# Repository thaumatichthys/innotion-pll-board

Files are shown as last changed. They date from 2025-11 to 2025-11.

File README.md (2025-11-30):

# ADF4158 + YSGM556006 Test Board  

**Thanks Mr GPT for (some parts of) the readme**

**5.5–6.0 GHz PLL/VCO Synthesizer w/ RP2040 Control**

This project is a small test board built around the **Analog Devices ADF4158** fractional-N PLL and the **Innotion YSGM556006** VCO module to generate RF signals in the **5.5–6.0 GHz** range.  
An **RP2040 microcontroller** drives the PLL over SPI, making it easy to test frequency sweeps, chirps, or single-tone synthesis.

## ✨ Features
- **ADF4158 PLL**
  - Fractional-N synthesizer  
  - Supports various shapes of ramps / chirps  

- **Innotion YSGM556006 VCO**
  - Very low cost VCO ($1.5/ea)
  - 5.5–6.0 GHz tuning range  
 
- **External (off-board) VCO Option**
  - SMA connectors expose VTUNE and VCO IN

- **RP2040 Controller**
  - Sends SPI commands for programming the PLL  
  - USB serial for sending commands / updating configs  

- **Other Board Components**
  - Loop filter for PLL stabilization  
  - Clean reference input stage (TCXO) 

## 📐 Purpose
This test board is designed for experimenting with PLL/VCO behavior at ~6 GHz.  
Typical use cases:

- Testing ADF4158 chirp/ramp features  
- Characterizing VCO tuning curve  
- LO generation for mixers or radar experiments  
- Measuring lock time, phase noise, loop stability  
- Learning / verifying SPI programming sequences for the ADF4158

## 🧠 How It Works
1. The **RP2040** boots and configures the ADF4158 via SPI.  
2. The ADF4158 sets the **divider ratio + ramp settings**.  
3. The loop filter drives the VCO’s **tuning voltage**, closing the PLL.  
4. The YSGM556006 outputs ~5.5–6 GHz RF.  
5. Lock status is monitored via **MUXOUT** exposed on the board.

## 🔌 SPI Interface (RP2040 → ADF4158)
- **MOSI** – PLL data input  
- **SCLK** – SPI clock  
- **LE** – Latch enable for register load  
- **MUXOUT** – Readable lock detect for debugging  

## ⚠️ Notes / Limitations
- The Innotion YSGM556006 is a very low cost ($1.5/ea) VCO, and has poor performance. This board was an attempt to test the feasibility of its use in a PLL.
- This test board is **not** a finalized RF product — it’s meant for bench characterization.  
- Ensure your RF chain and measurement equipment can safely handle 5–6 GHz at around 0 dBm.

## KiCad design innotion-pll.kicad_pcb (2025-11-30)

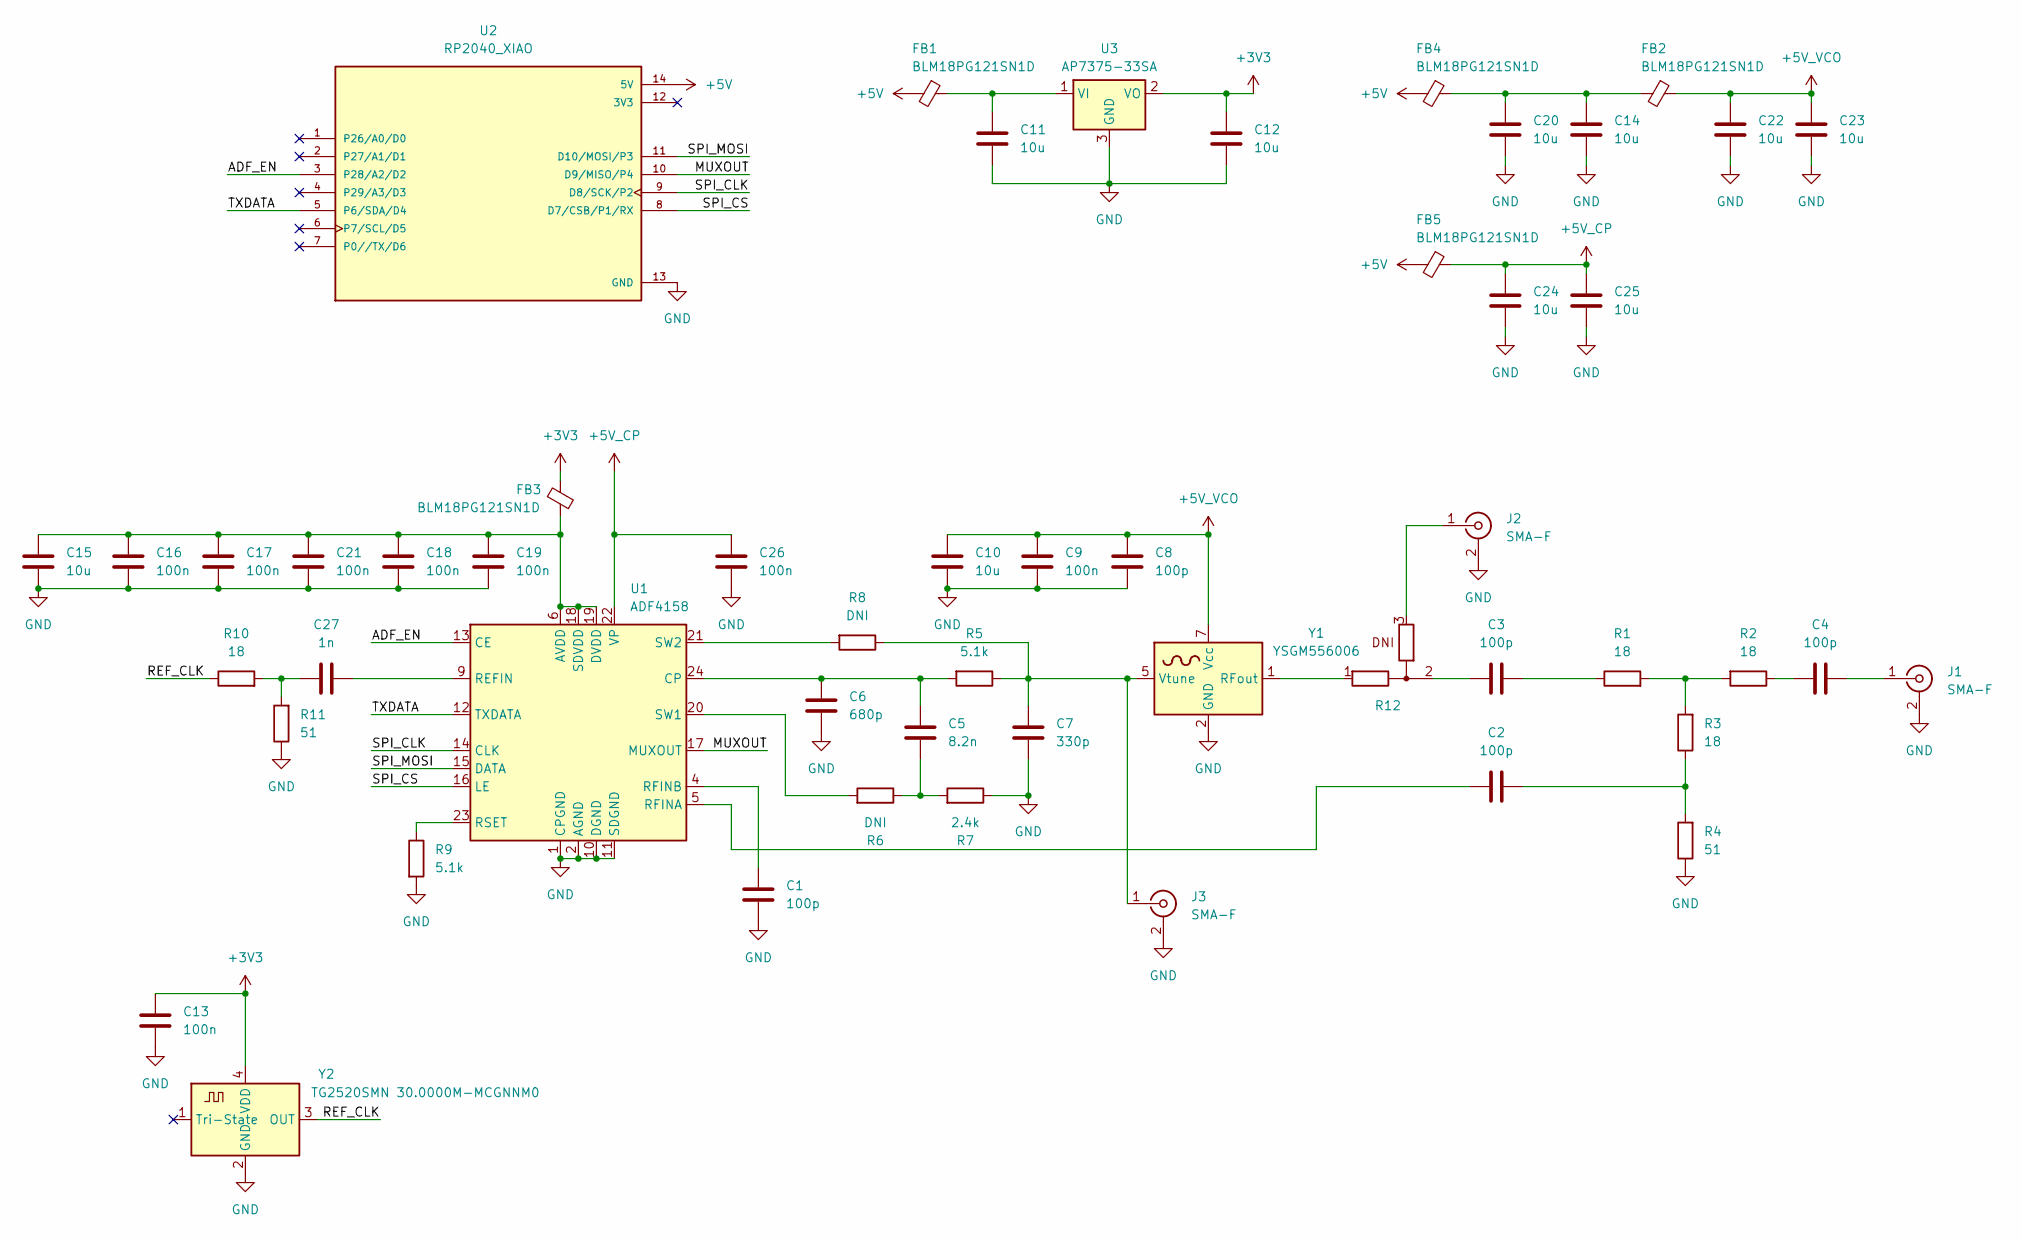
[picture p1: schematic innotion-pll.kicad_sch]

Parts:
C1, C2, C3, C4, C8: 100p; C_0402_1005Metric
C5: 8.2n; C_0402_1005Metric
C6: 680p; C_0402_1005Metric
C7: 330p; C_0402_1005Metric
C9, C13, C16, C17, C18, C19, C21, C26: 100n; C_0402_1005Metric
C10, C11, C12, C14, C15, C20, C22, C23, C24, C25: 10u; C_0805_2012Metric
C27: 1n; C_0402_1005Metric
FB1, FB2, FB3, FB4, FB5: BLM18PG121SN1D; L_0603_1608Metric_Pad1.05x0.95mm_HandSolder
J1, J2, J3: SMA-F; ADAMTECH_RF2-143-T-17-50-G
R1, R2, R3, R10: 18; R_0402_1005Metric
R4, R11: 51; R_0402_1005Metric
R5, R9: 5.1k; R_0402_1005Metric
R6, R8: DNI; R_0402_1005Metric
R7: 2.4k; R_0402_1005Metric
R12: R_0402_SELECT_MIRRORED
U1: ADF4158; LFCSP-24-1EP_4x4mm_P0.5mm_EP2.5x2.5mm
U2: RP2040_XIAO; MODULE_102010428; PARTREV 1.3
U3: AP7375-33SA; SOT-23
Y1: YSGM556006; INNOTION_VCO_MODULE_7x9mm
Y2: TG2520SMN 30.0000M-MCGNNM0; Oscillator_SMD_SeikoEpson_TG2520SMN-xxx-xxxxxx-4Pin_2.5x2.0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

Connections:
+3V3: C12.2, C13.2, FB3.1, U3.2 (VO), Y2.4 (VDD)
+5V: FB1.2, FB4.2, FB5.2, U2.14 (5V)
+5V_CP: C24.2, C25.2, C26.2, FB5.1, U1.22 (VP)
+5V_VCO: C8.2, C9.2, C10.2, C22.2, C23.2, FB2.1, Y1.7 (Vcc)
/ADF_EN: U1.13 (CE), U2.3 (P28/A2/D2)
/MUXOUT: U1.17 (MUXOUT), U2.10 (D9/MISO/P4)
/REF_CLK: R10.1, Y2.3 (OUT)
/SPI_CLK: U1.14 (CLK), U2.9 (D8/SCK/P2)
/SPI_CS: U1.16 (LE), U2.8 (D7/CSB/P1/RX)
/SPI_MOSI: U1.15 (DATA), U2.11 (D10/MOSI/P3)
/TXDATA: U1.12 (TXDATA), U2.5 (P6/SDA/D4)
GND: C1.1, C6.1, C7.1, C8.1, C9.1, C10.1, C11.1, C12.1, C13.1, C14.1, C15.1, C16.1, C17.1, C18.1, C19.1, C20.1, C21.1, C22.1, C23.1, C24.1, C25.1, C26.1, J1.2 (Ext), J2.2 (Ext), J3.2 (Ext), R4.1, R7.1, R9.2, R11.1, U1.1 (CPGND), U1.2 (AGND), U1.3 (AGND), U1.10 (DGND), U1.11 (SDGND), U1.25 (AGND), U2.13 (GND), U3.3 (GND), Y1.2 (GND), Y1.3 (GND), Y1.4 (GND), Y1.6 (GND), Y1.8 (GND), Y2.2 (GND)
unnamed: C2.2, R3.1, R4.2
unnamed: C3.1, R12.2
unnamed: C3.2, R1.1
unnamed: C4.1, R2.1
unnamed: C5.1, R6.1, R7.2
unnamed: C14.2, C20.2, FB2.2, FB4.1
unnamed: C27.2, R10.2, R11.2
unnamed: C4.2, J1.1 (In)
unnamed: J2.1 (In), R12.3
unnamed: C7.2, J3.1 (In), R5.1, R8.1, Y1.5 (Vtune)
unnamed: R1.2, R2.2, R3.2
unnamed: C5.2, C6.2, R5.2, U1.24 (CP)
unnamed: C15.2, C16.2, C17.2, C18.2, C19.2, C21.2, FB3.2, U1.6 (AVDD), U1.7 (AVDD), U1.8 (AVDD), U1.18 (SDVDD), U1.19 (DVDD)
unnamed: C27.1, U1.9 (REFIN)
unnamed: C2.1, U1.5 (RFINA)
unnamed: C1.2, U1.4 (RFINB)
unnamed: R9.1, U1.23 (RSET)
unnamed: R6.2, U1.20 (SW1)
unnamed: R8.2, U1.21 (SW2)
unnamed: C11.2, FB1.1, U3.1 (VI)
unnamed: R12.1, Y1.1 (RFout)

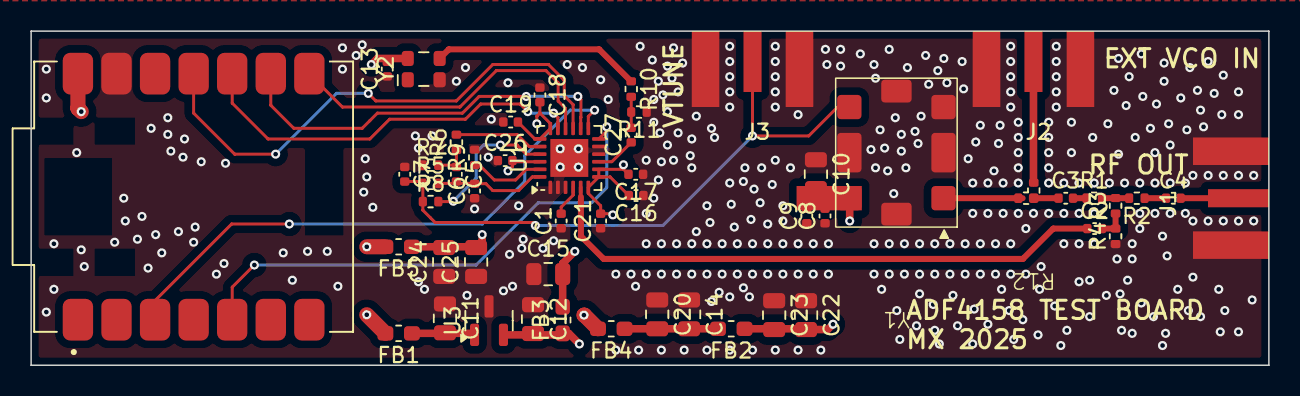
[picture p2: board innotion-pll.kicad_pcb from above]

Board: 4 copper layers, 81.5 x 22.0 mm, 52 parts (0 on the bottom side), 33 nets.
